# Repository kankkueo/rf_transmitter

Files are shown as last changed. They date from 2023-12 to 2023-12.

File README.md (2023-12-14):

# RF transmitter

## Contributors

### [Elmo Kankkunen](https://github.com/kankkueo)

### [Miikka Mäki](https://github.com/mimimaki)

### [Visa Kurvi](https://github.com/visakurvi)

## Description

The project is very low power and thus legal, but be aware of your local laws and regulations!

RF transmitter project for Aalto university course Elektroniikkapaja. The transmitter consists of a digital and analog circuits. The digital circuit has an ATMEGA328 microcontroller, which controls a digital potentiometer. This potentiometer sets the voltage level of an MAX2606 VCO input. This is how the transmitter frequency is controlled. Audio from a microphone is then modulated to this FM-signal. 

## Screenshots

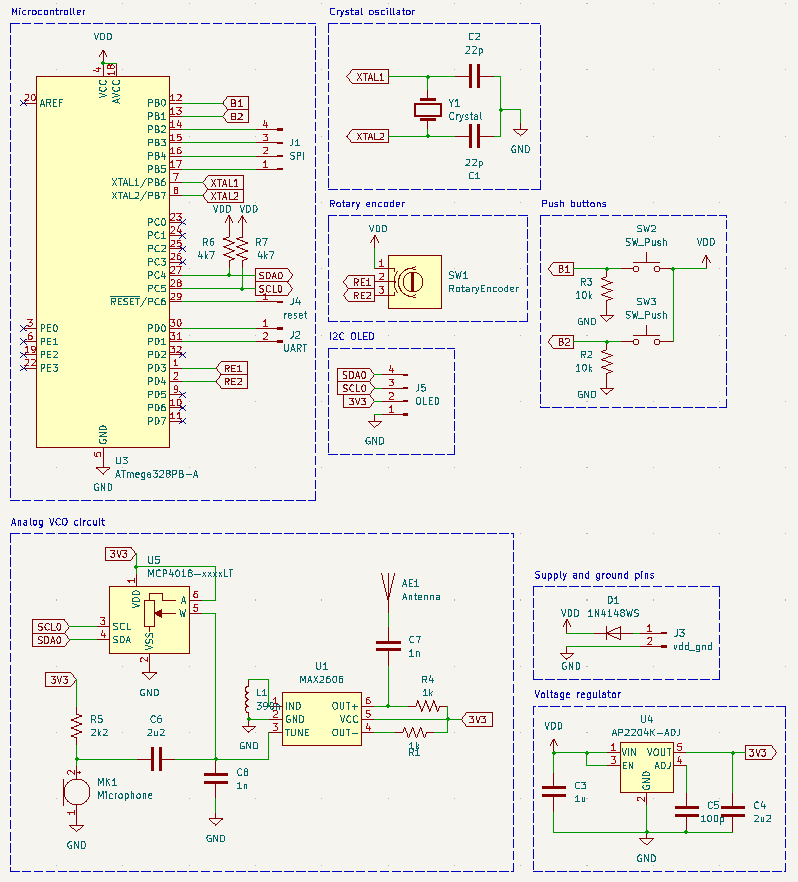
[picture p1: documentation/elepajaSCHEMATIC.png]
Schematic

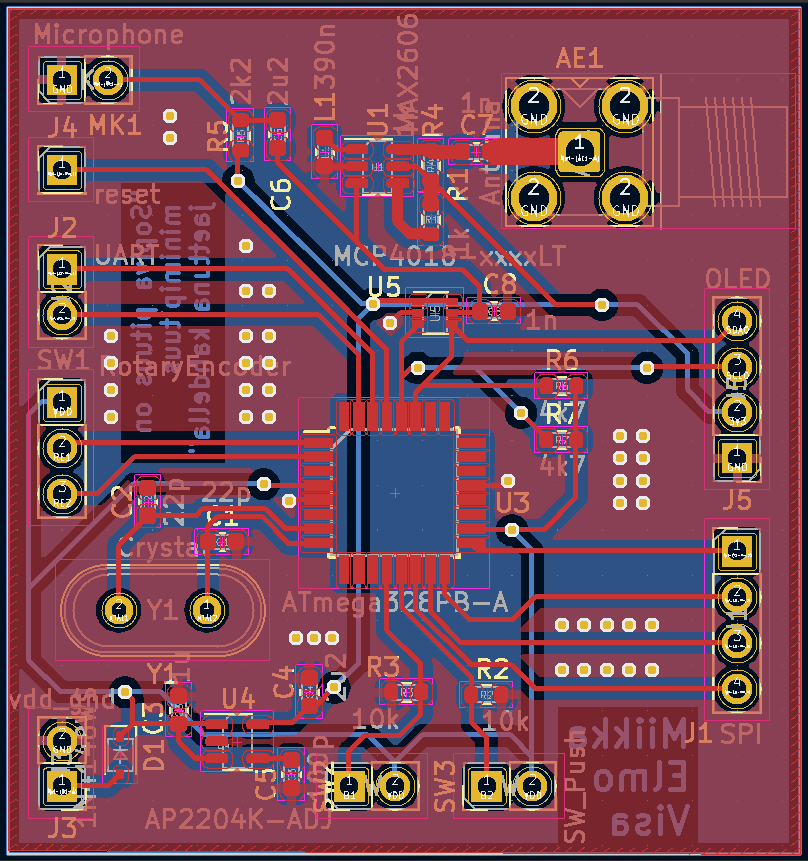
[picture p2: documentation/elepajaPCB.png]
PCB

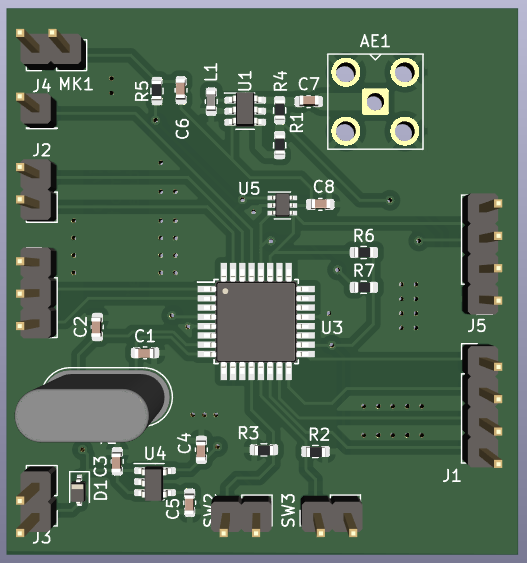
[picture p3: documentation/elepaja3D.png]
3D-viewer


## SDR++ captured demo

[Demo video](https://drive.google.com/file/d/1DeKwweD5EkPlx5URQ9tuIAPdqHnWOvnQ/view?usp=sharing/)

## License

MIT License

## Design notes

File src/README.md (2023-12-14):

## Software
This software and Makefile was designed to work with the 
Atmega328p MCU. The programming is done through the SPI bus
using an Arduino Uno as an in-system programmer.

[This](https://github.com/Sovichea/avr-i2c-library) library was used for the i2c communication.

### Requirements
- avr-gcc
- avr-libc
- avrdude

### Compilation
`make` to compile

`make upload` to upload the code to the MCU

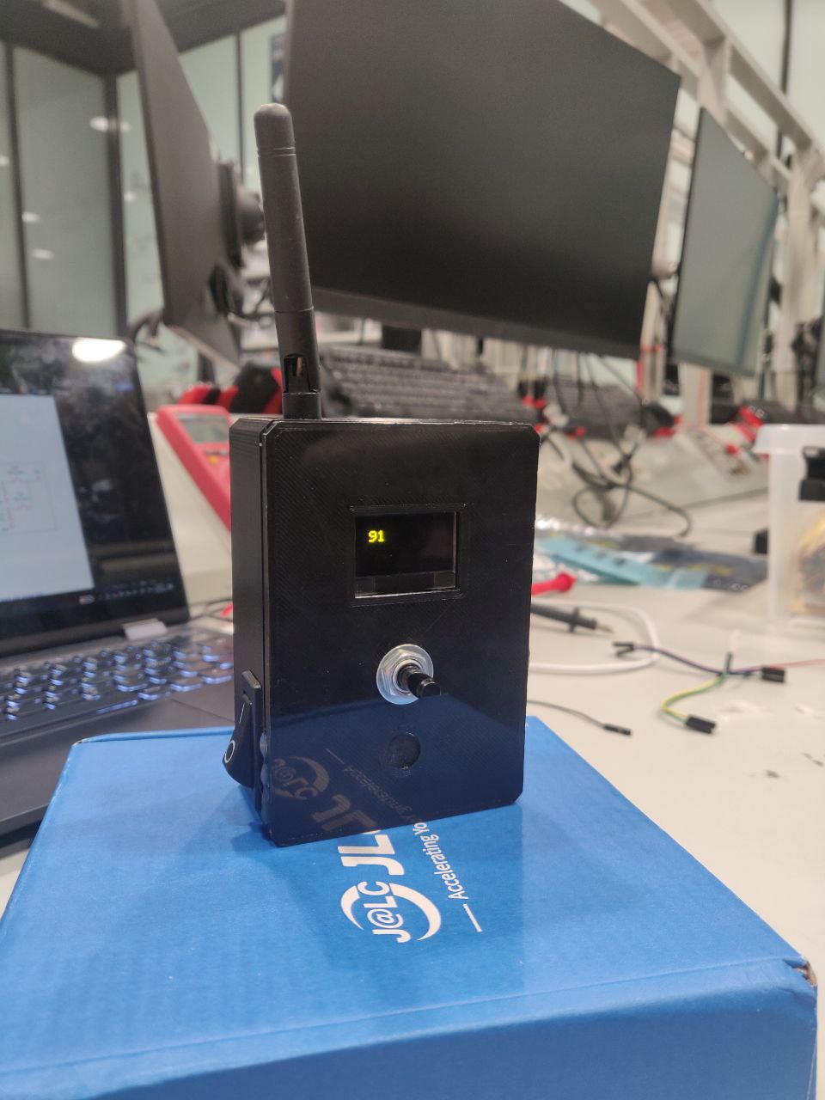
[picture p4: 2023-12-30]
documentation/final_product.jpg

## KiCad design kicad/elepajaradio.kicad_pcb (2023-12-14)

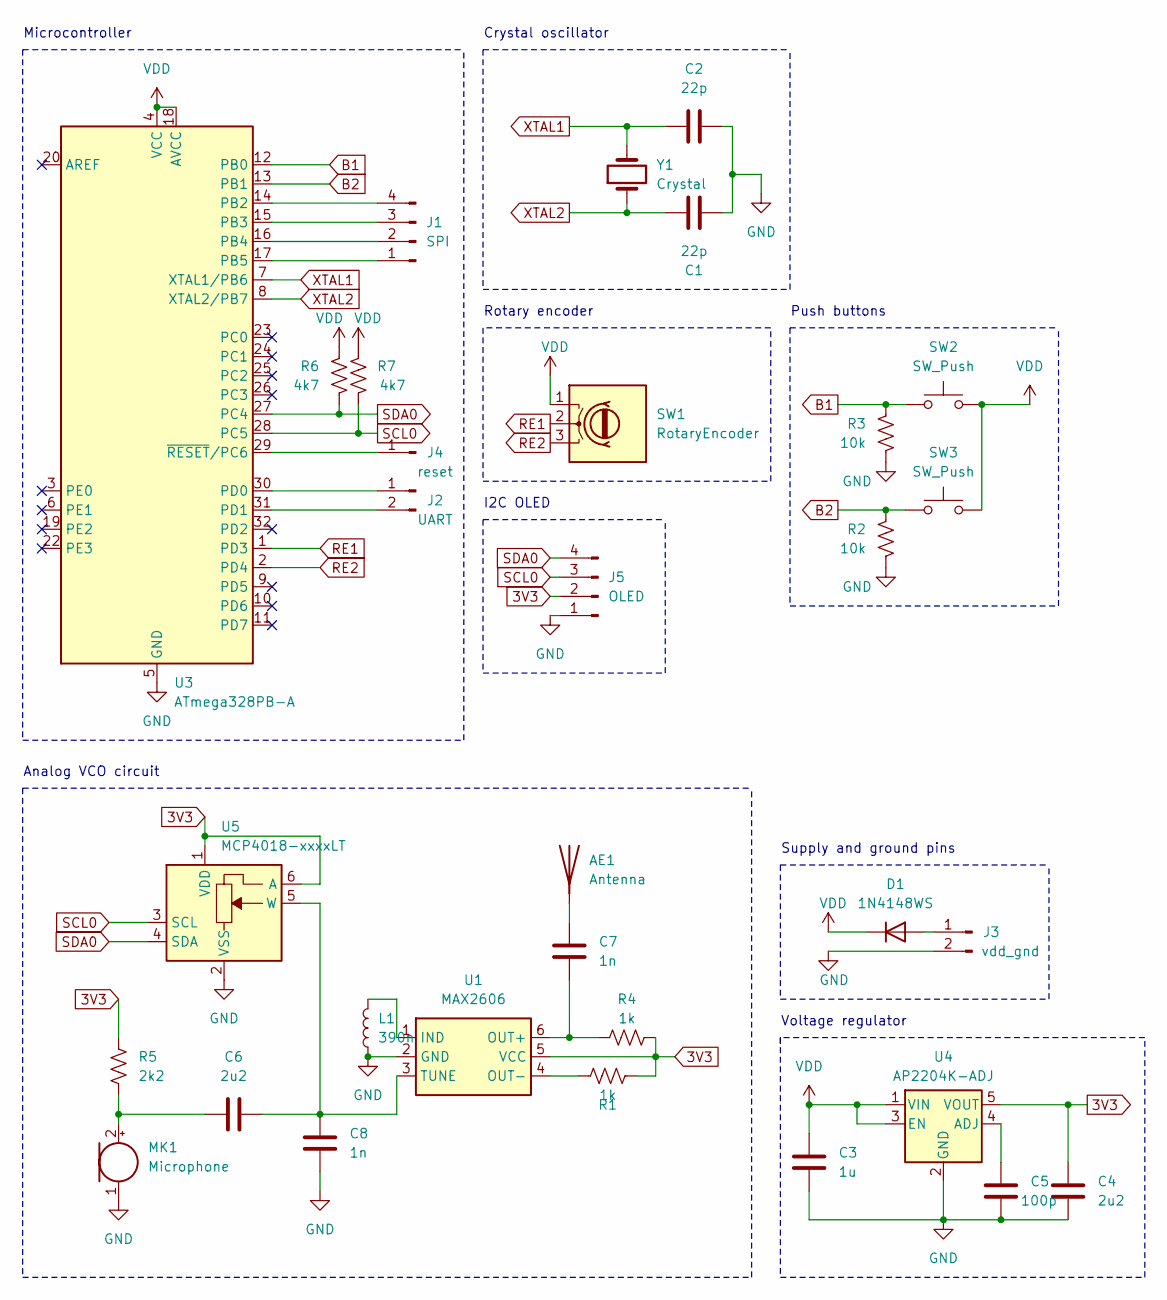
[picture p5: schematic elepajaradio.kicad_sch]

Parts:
AE1: Antenna; SMA_Amphenol_901-143_Horizontal
C1, C2: 22p; C_0603_1608Metric
C3: 1u; C_0603_1608Metric
C4, C6: 2u2; C_0603_1608Metric
C5: 100p; C_0603_1608Metric
C7, C8: 1n; C_0603_1608Metric
D1: 1N4148WS; D_SOD-323
J1: SPI; PinHeader_1x04_P2.54mm_Vertical
J2: UART; PinHeader_1x02_P2.54mm_Vertical
J3: vdd_gnd; PinHeader_1x02_P2.54mm_Vertical
J4: reset; PinHeader_1x01_P2.54mm_Vertical
J5: OLED; PinHeader_1x04_P2.54mm_Vertical
L1: 390n; L_0603_1608Metric
MK1: Microphone; PinHeader_1x02_P2.54mm_Vertical
R1, R4: 1k; R_0603_1608Metric
R2, R3: 10k; R_0603_1608Metric
R5: 2k2; R_0603_1608Metric
R6, R7: 4k7; R_0603_1608Metric
SW1: RotaryEncoder; PinHeader_1x03_P2.54mm_Vertical
SW2, SW3: SW_Push; PinHeader_1x02_P2.54mm_Vertical
U1: MAX2606; SOT-23-6
U3: ATmega328PB-A; TQFP-32_7x7mm_P0.8mm
U4: AP2204K-ADJ; SOT-23-5
U5: MCP4018-xxxxLT; SOT-363_SC-70-6
Y1: Crystal; Crystal_HC18-U_Vertical

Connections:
3V3: C4.1, J5.2, R1.1, R4.1, R5.2, U1.5 (VCC), U4.5 (VOUT), U5.1 (VDD), U5.6 (A)
B1: R3.2, SW2.1, U3.12 (PB0)
B2: R2.2, SW3.1, U3.13 (PB1)
GND: AE1.2, C1.2, C2.2, C3.2, C4.2, C5.2, C8.2, J3.2, J5.1, L1.1, MK1.1 (-), R2.1, R3.1, U1.2 (GND), U3.5 (GND), U3.21 (GND), U4.2 (GND), U5.2 (VSS)
unnamed: AE1.1 (A), C7.1
unnamed: D1.2 (A), J3.1
unnamed: J1.1, U3.17 (PB5)
unnamed: J1.2, U3.16 (PB4)
unnamed: J1.3, U3.15 (PB3)
unnamed: J1.4, U3.14 (PB2)
unnamed: J2.1, U3.30 (PD0)
unnamed: J2.2, U3.31 (PD1)
unnamed: J4.1, U3.29 (~RESET/PC6)
unnamed: C6.1, MK1.2 (+), R5.1
unnamed: L1.2, U1.1 (IND)
unnamed: C7.2, R4.2, U1.6 (OUT+)
unnamed: R1.2, U1.4 (OUT-)
unnamed: C6.2, C8.1, U1.3 (TUNE), U5.5 (W)
unnamed: C5.1, U4.4 (ADJ)
RE1: SW1.2, U3.1 (PD3)
RE2: SW1.3, U3.2 (PD4)
SCL0: J5.3, R7.1, U3.28 (PC5), U5.3 (SCL)
SDA0: J5.4, R6.1, U3.27 (PC4), U5.4 (SDA)
VDD: C3.1, D1.1 (K), R6.2, R7.2, SW1.1, SW2.2, SW3.2, U3.4 (VCC), U3.18 (AVCC), U4.1 (VIN), U4.3 (EN)
XTAL1: C2.1, U3.7 (XTAL1/PB6), Y1.2
XTAL2: C1.1, U3.8 (XTAL2/PB7), Y1.1

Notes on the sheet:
Microcontroller
Analog VCO circuit
Crystal oscillator
I2C OLED
Push buttons
Supply and ground pins
Rotary encoder
Voltage regulator

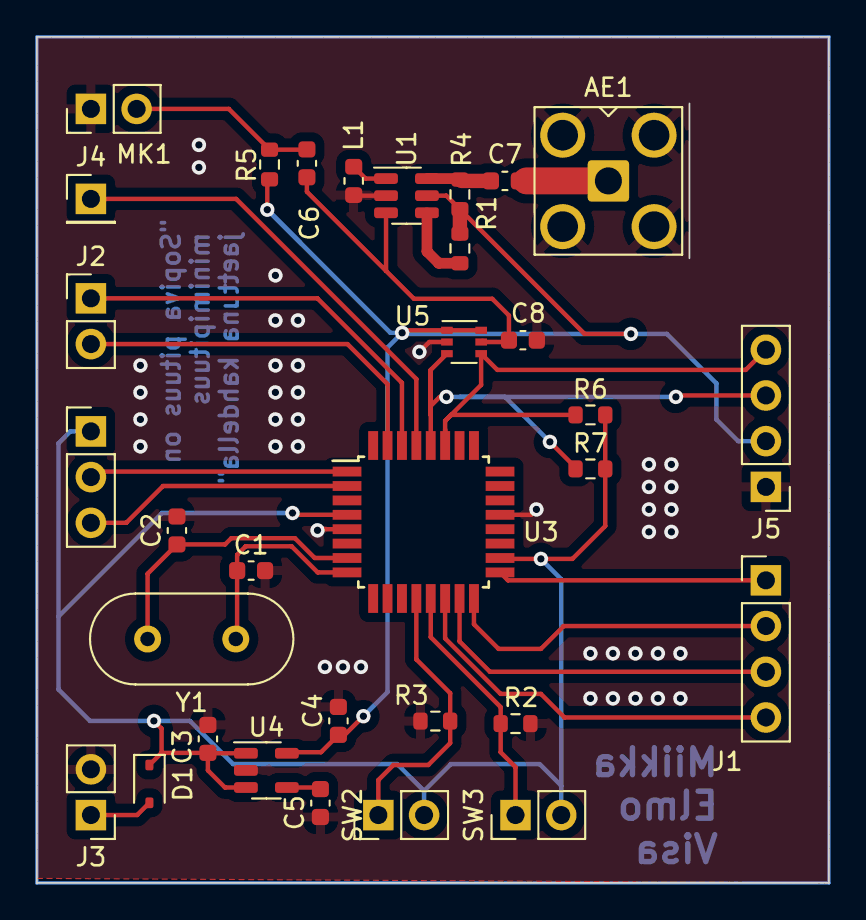
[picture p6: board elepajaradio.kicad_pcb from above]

Board: 2 copper layers, 44.0 x 47.0 mm, 32 parts (0 on the bottom side), 26 nets.

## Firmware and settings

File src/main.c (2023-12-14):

#include <avr/io.h>
#include <util/delay.h>
#include <avr/interrupt.h>
#include <avr/pgmspace.h>

/*
* twi_master.c
*
* Created: 09-Jun-19 11:20:17 AM
*  Author: TEP SOVICHEA
*/

#include "twi_master.h"

static ret_code_t tw_start(void)
{
	/* Send START condition */
#if DEBUG_LOG
	printf(BG "Send START condition..." RESET);
#endif
	TWCR =  (1 << TWINT) | (1 << TWEN) | (1 << TWSTA);
	
	/* Wait for TWINT flag to set */
	while (!(TWCR & (1 << TWINT)));
	
	/* Check error */
	if (TW_STATUS != TW_START && TW_STATUS != TW_REP_START)
	{
#if DEBUG_LOG
		printf("\n");
#endif
		return TW_STATUS;
	}
	
#if DEBUG_LOG
	printf("SUCCESS\n");
#endif
	return SUCCESS;
}


static void tw_stop(void)
{
	/* Send STOP condition */
#if DEBUG_LOG
	puts(BG "Send STOP condition." RESET);
#endif
	TWCR = (1 << TWINT) | (1 << TWEN) | (1 << TWSTO);
}


static ret_code_t tw_write_sla(uint8_t sla)
{
	/* Transmit slave address with read/write flag */
#if DEBUG_LOG
	printf(BG "Write SLA + R/W: 0x%02X..." RESET, sla);
#endif
	TWDR = sla;
	TWCR = (1 << TWINT) | (1 << TWEN);
	
	/* Wait for TWINT flag to set */
	while (!(TWCR & (1 << TWINT)));
	if (TW_STATUS != TW_MT_SLA_ACK && TW_STATUS != TW_MR_SLA_ACK)
	{
#if DEBUG_LOG
		printf("\n");
#endif
		return TW_STATUS;
	}

#if DEBUG_LOG
	printf("SUCCESS\n");
#endif
	return SUCCESS;
}


static ret_code_t tw_write(uint8_t data)
{
	/* Transmit 1 byte*/
#if DEBUG_LOG
	printf(BG "Write data byte: 0x%02X..." RESET, data);
#endif
	TWDR = data;
	TWCR = (1 << TWINT) | (1 << TWEN);
	
	/* Wait for TWINT flag to set */
	while (!(TWCR & (1 << TWINT)));
	if (TW_STATUS != TW_MT_DATA_ACK)
	{
#if DEBUG_LOG
		printf("\n");
#endif
		return TW_STATUS;
	}
	
#if DEBUG_LOG
	printf("SUCCESS\n");
#endif
	return SUCCESS;
}


static uint8_t tw_read(bool read_ack)
{
	if (read_ack)
	{
		TWCR = (1 << TWINT) | (1 << TWEN) | (1 << TWEA);
		while (!(TWCR & (1 << TWINT)));
		if (TW_STATUS != TW_MR_DATA_ACK)
		{
			return TW_STATUS;
		}
	}
	else
	{
		TWCR = (1 << TWINT) | (1 << TWEN);
		while (!(TWCR & (1 << TWINT)));
		if (TW_STATUS != TW_MR_DATA_NACK)
		{
			return TW_STATUS;
		}
	}
	uint8_t data = TWDR;
#if DEBUG_LOG
	printf(BG "Read data byte: 0x%02X\n" RESET, data);
#endif
	return data;
}


void tw_init(twi_freq_mode_t twi_freq_mode, bool pullup_en)
{
	DDRC  |= (1 << TW_SDA_PIN) | (1 << TW_SCL_PIN);
	if (pullup_en)
	{
#if DEBUG_LOG
		puts(BG "Enable pull-up resistor." RESET);
#endif
		PORTC |= (1 << TW_SDA_PIN) | (1 << TW_SCL_PIN);
	}
	else
	{
		PORTC &= ~((1 << TW_SDA_PIN) | (1 << TW_SCL_PIN));
	}
	DDRC  &= ~((1 << TW_SDA_PIN) | (1 << TW_SCL_PIN));
	
	switch (twi_freq_mode)
	{
		case TW_FREQ_100K:
		/* Set bit rate register 72 and prescaler to 1 resulting in
		SCL_freq = 16MHz/(16 + 2*72*1) = 100KHz	*/
		TWBR = 72;
		break;
		
		case TW_FREQ_250K:
		/* Set bit rate register 24 and prescaler to 1 resulting in
		SCL_freq = 16MHz/(16 + 2*24*1) = 250KHz	*/
		TWBR = 24;
		break;
		
		case TW_FREQ_400K:
		/* Set bit rate register 12 and prescaler to 1 resulting in
		SCL_freq = 16MHz/(16 + 2*12*1) = 400KHz	*/
		TWBR = 12;
		break;
		
		default: break;
	}
}


ret_code_t tw_master_transmit(uint8_t slave_addr, uint8_t* p_data, uint8_t len, bool repeat_start)
{
	ret_code_t error_code;
	
	/* Send START condition */
	error_code = tw_start();
	if (error_code != SUCCESS)
	{
		return error_code;
	}
	
	/* Send slave address with WRITE flag */
	error_code = tw_write_sla(TW_SLA_W(slave_addr));
	if (error_code != SUCCESS)
	{
		return error_code;
	}
	
	/* Send data byte in single or burst mode */
	for (int i = 0; i < len; ++i)
	{
		error_code = tw_write(p_data[i]);
		if (error_code != SUCCESS)
		{
			return error_code;
		}
	}
	
	if (!repeat_start)
	{
		/* Send STOP condition */
		tw_stop();
	}
	
	return SUCCESS;
}


ret_code_t tw_master_receive(uint8_t slave_addr, uint8_t* p_data, uint8_t len)
{
	ret_code_t error_code;
	
	/* Send START condition */
	error_code = tw_start();
	if (error_code != SUCCESS)
	{
		return error_code;
	}
	
	/* Write slave address with READ flag */
	error_code = tw_write_sla(TW_SLA_R(slave_addr));
	if (error_code != SUCCESS)
	{
		return error_code;
	}
	
	/* Read single or multiple data byte and send ack */
	for (int i = 0; i < len-1; ++i)
	{
		p_data[i] = tw_read(TW_READ_ACK);
	}
	p_data[len-1] = tw_read(TW_READ_NACK);
	
	/* Send STOP condition */
	tw_stop();
	
	return SUCCESS;
}

/*  Oled display driver
 */

void startOLED() {
    char disp = 0xa4;
    tw_master_transmit(0x3c, &disp, 1, false);

    disp = 0xa6;
    tw_master_transmit(0x3c, &disp, 1, false);

    disp = 0xaf;
    tw_master_transmit(0x3c, &disp, 1, false);
}

int main(void) {

    DDRB = 0;
    tw_start();
    tw_init(TW_FREQ_100K, false);

    startOLED();

    char selected = 7;

    char display_freqs[14][5] = {
        {'8', '2', '.', '6', '4'},
        {'8', '4', '.', '7', '0'},
        {'8', '6', '.', '7', '6'},
        {'8', '8', '.', '8', '3'},
        {'9', '0', '.', '9', '7'},
        {'9', '2', '.', '9', '3'},
        {'9', '4', '.', '9', '9'},
        {'9', '7', '.', '0', '5'},
        {'9', '9', '.', '1', '0'},
        {'1', '0', '1', '.', '2'},
        {'1', '0', '3', '.', '2'},
        {'1', '0', '5', '.', '3'},
        {'1', '0', '7', '.', '3'},
        {'1', '0', '9', '.', '4'},
    };

    char pot_values[14] = {
        0, 10, 20, 30, 40, 50, 60, 70, 80, 90, 100, 110, 120, 127
    };

    while(1) {

        // Button 1
        if (PINB & (1 << 0)) {
            if (selected <= 12) {
                selected++;
            }
            tw_master_transmit(0x2f, &pot_values[selected], 1, false);
            _delay_ms(100);   
        }
        // Button 2
        if (PINB & (1 << 1)) {
            if (selected >= 1) {
                selected--;
            }
            tw_master_transmit(0x2f, &pot_values[selected], 1, false);
            _delay_ms(100);   
        }

        tw_master_transmit(0x3c, &display_freqs[selected][0] , 5, false);

        _delay_ms(10);   

    }

    return 0;
}

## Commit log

2023-10-23 lisätään kicad projekti
    [elepajaradio.kicad_pcb, elepajaradio.kicad_sch]
2023-10-26 kicad update
    [elepajaradio.kicad_sch]
2023-10-26 adding doc file and spice simulation file
    [elepajaradio.kicad_sch]
2023-10-30 new circuit added
    [elepajaradio.kicad_sch]
2023-11-07 initial pcb design and adding antenna connector
    [elepajaradio.kicad_pcb, elepajaradio.kicad_sch]
2023-11-09 resized transmission line for pcb
    [elepajaradio.kicad_pcb]
2023-11-09 sized transmission line v2
    [elepajaradio.kicad_pcb, elepajaradio.kicad_sch]
2023-11-09 adding PCB gbr and drl files
    [elepajaradio-B_Adhesive.gbr, elepajaradio-B_Courtyard.gbr, elepajaradio-B_Cu.gbr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]
2023-11-25 fixes on new branch for 3v3 node
    [elepajaradio.kicad_pcb, elepajaradio.kicad_sch]
2023-11-26 fixing vco output nodes
    [elepajaradio.kicad_pcb, elepajaradio.kicad_sch]
2023-11-26 schematic updates for documentation
    [elepajaradio.kicad_pcb, elepajaradio.kicad_sch]
2023-11-28 adding 3D model
    [box.scad]
2023-11-28 updates for second order
    [elepajaradio.kicad_pcb, elepajaradio.kicad_sch]
2023-12-02 kicad gitignore
2023-12-04 removing unnecessary files
    [box.scad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]
2023-12-04 cleaning git
    [elepajaradio_2.kicad_sch]
2023-12-07 combining i2cmaster.c and main.c
2023-12-08 new i2c lib
2023-12-14 pull-up resistors and diode added
    [elepajaradio-B_Cu.gbl, elepajaradio-B_Mask.gbs, elepajaradio-B_Paste.gbp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]
2023-12-14 fixing text
    [elepajaradio.kicad_pcb]
2023-12-14 pcb fix
    [elepajaradio.kicad_pcb]
